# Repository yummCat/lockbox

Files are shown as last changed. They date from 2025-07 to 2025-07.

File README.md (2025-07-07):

# lockbox

The latest brilliant innovation we were able to come up with, was a box, that locks! 🤯

This device was meant to be small and cute, and importantly baby friendly. Designed for baby professionals, colloquially known as "Boss Babies" this device is meant to be carried around in a briefcase, unlocked with an RFID badge and four digit pin. In the process we learned a lot about RFID and how encryption worked(when we got sidetracked).

This project started with a schematic:



Next we made the pcb design:



Next we made the 3d model:


WhatsApp Image 2025-07-02 at 21 14 29_6d6b2fa8
WhatsApp Image 2025-07-07 at 18 49 21_a0b8ef6a

Lastly the BOM:


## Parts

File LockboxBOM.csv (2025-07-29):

Lockbox | Quantity | Net Cost | Links to buy stuff :)) | Shipping
Arduino Uno v3 | 1 | 14 | https://www.amazon.com/dp/B0B6VV7MS7?sp_csd=d2lkZ2V0TmFtZT1zcF9ocXBfc2hhcmVk | $0
RFID | 1 | 10 | https://www.amazon.com/HiLetgo-3pcs-RFID-Kit-Raspberry/dp/B07VLDSYRW/ | $0
Switches | 10 | 2.5 | https://www.adafruit.com/product/1119 | $4.90
Resistors | irrelevant | 6.5 | https://www.amazon.com/dp/B09N7NKX2Jhttps://www.amazon.com/California-JOS-Carbon-Resistor-Tolerance/dp/B0BR66LHWH/r | $0
Mosfet | 1 | 0.15 | https://www.addicore.com/products/2n7000-logic-level-n-channel-mosfet?variant=45759492948285 | $8
Charger | 1 | 1.25 | https://www.addicore.com/products/tp4056-tc4056a-lithium-battery-charger-and-protection-module | $0
Capacitors | irrelevant | 8 | (Prob can find cheaper)https://www.amazon.com/dp/B0DR8QRW1L/ref=sspa_dk_detail_5 | $0
Boost converter | 1 | 1.5 | https://www.addicore.com/products/mt3608-step-up-adjustable-dc-dc-switching-boost-converter | $0
Diodes | 3 | NA | NA
LiPO battery | 1 | 5.5 | (Prob can find cheaper)https://www.digikey.com/en/products/detail/us-electronics-inc./USE-702528-500PCBJST/15781479 | $20
Lock thing | 1 | 9 | https://www.amazon.com/Uxcell-a14092600ux0438-Actuator-Solenoid-Electromagnet/dp/B013DR655A/ | $0
3D printing |  | 27 |  | $0
Total: | $118 | 85.4 |  | $33

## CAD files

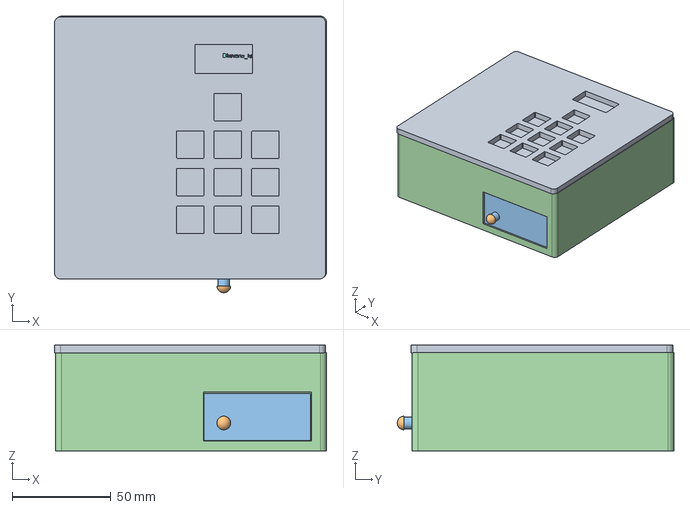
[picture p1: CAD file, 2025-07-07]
cad/Lockbox_complete.step
138.0 x 140.3 x 53.7 mm

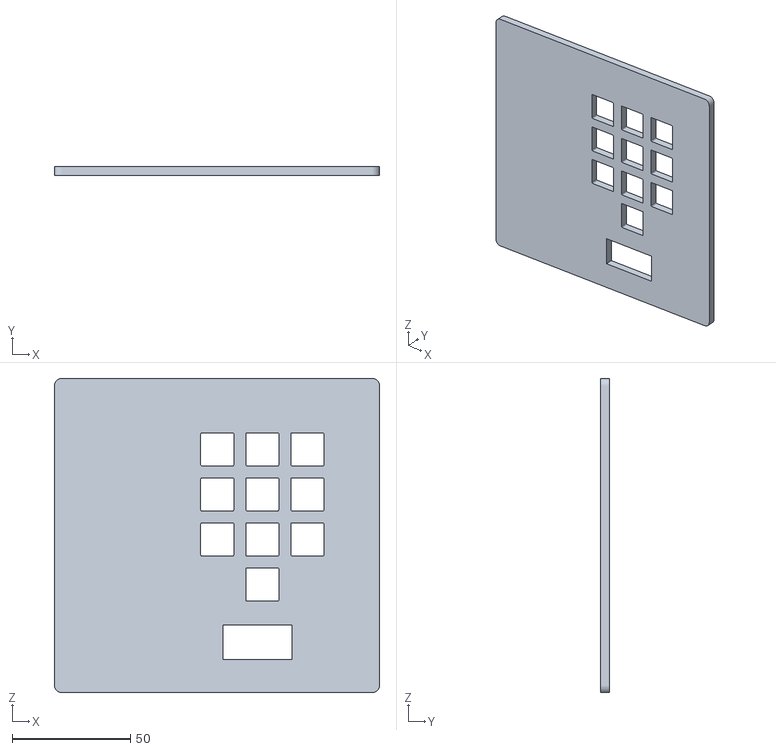
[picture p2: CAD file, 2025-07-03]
production/Lockbox_top.stl
137.5 x 4.00 x 132.8

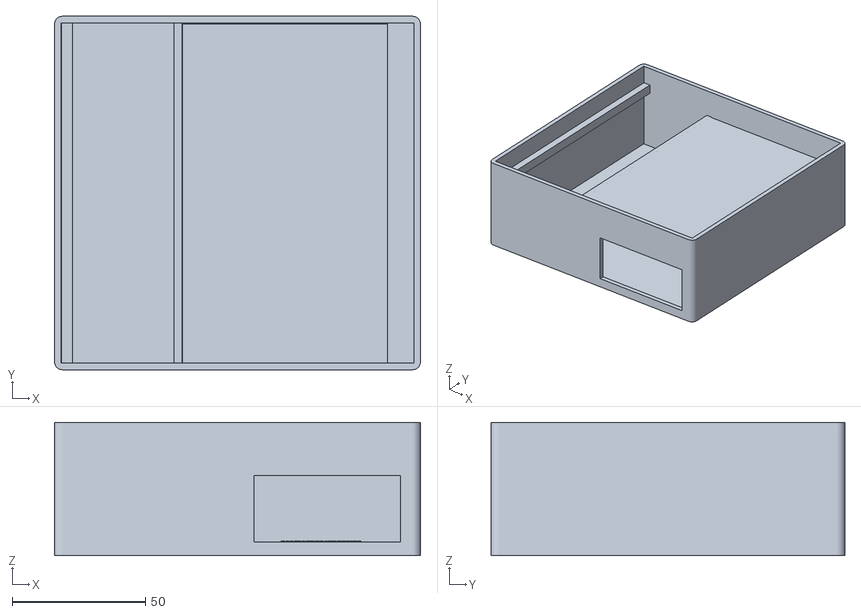
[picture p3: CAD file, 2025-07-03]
cad/Lockbox.stl
137.5 x 132.9 x 50.0

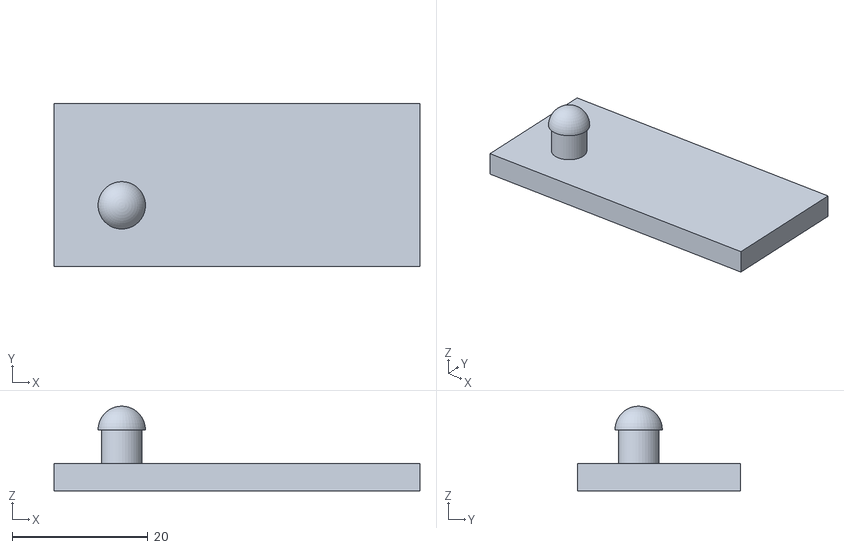
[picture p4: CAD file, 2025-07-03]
production/Door_for_locbox.stl
54.0 x 24.0 x 12.5

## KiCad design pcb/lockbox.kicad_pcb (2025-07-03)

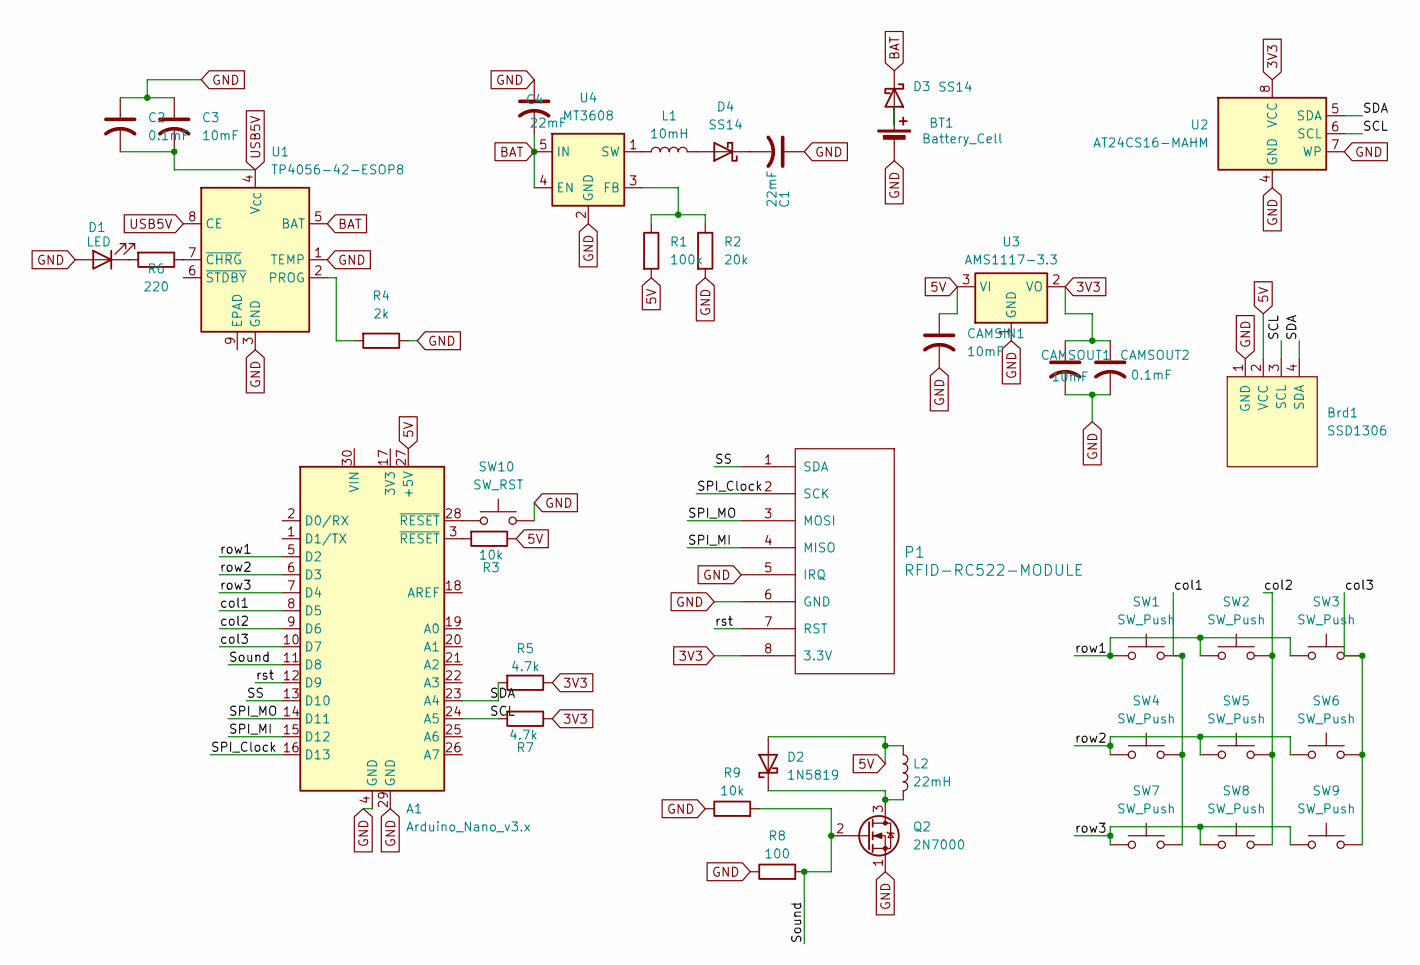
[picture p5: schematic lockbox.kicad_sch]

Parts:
A1: Arduino_Nano_v3.x; Arduino_Nano
BT1: Battery_Cell; JST_PH_S2B-PH-K_1x02_P2.00mm_Horizontal
Brd1: SSD1306; Adafruit_SSD1306
C1, C4: 22mF; CP_Radial_D5.0mm_P2.00mm
C2: 0.1mF; CP_Radial_D5.0mm_P2.50mm
C3: 10mF; CP_Radial_D5.0mm_P2.00mm
CAMSIN1: 10mF; CP_Radial_D5.0mm_P2.00mm
CAMSOUT1: 10mF; CP_Radial_D5.0mm_P2.00mm
CAMSOUT2: 0.1mF; CP_Radial_D5.0mm_P2.50mm
D1: LED; LED_D5.0mm
D2: 1N5819; D_DO-41_SOD81_P10.16mm_Horizontal
D3, D4: SS14; D_SMA
L1: 10mH; L_Axial_L26.0mm_D9.0mm_P5.08mm_Vertical_Fastron_77A
L2: 22mH; L_Axial_L26.0mm_D9.0mm_P5.08mm_Vertical_Fastron_77A
P1: RFID-RC522-MODULE; RC522_I2C_B30x20mm
Q2: 2N7000; TO-92L_Inline_Wide
R1: 100k; R_Axial_DIN0207_L6.3mm_D2.5mm_P7.62mm_Horizontal
R2: 20k; R_Axial_DIN0207_L6.3mm_D2.5mm_P7.62mm_Horizontal
R3, R9: 10k; R_Axial_DIN0207_L6.3mm_D2.5mm_P7.62mm_Horizontal
R4: 2k; R_Axial_DIN0207_L6.3mm_D2.5mm_P7.62mm_Horizontal
R5, R7: 4.7k; R_Axial_DIN0207_L6.3mm_D2.5mm_P7.62mm_Horizontal
R6: 220; R_Axial_DIN0207_L6.3mm_D2.5mm_P7.62mm_Horizontal
R8: 100; R_Axial_DIN0207_L6.3mm_D2.5mm_P7.62mm_Horizontal
SW1, SW2, SW3, SW4, SW5, SW6, SW7, SW8, SW9: SW_Push; SW_Cherry_MX_1.00u_PCB
SW10: SW_RST; SW_Cherry_MX_1.00u_PCB
U1: TP4056-42-ESOP8; SOIC-8-1EP_3.9x4.9mm_P1.27mm_EP2.41x3.3mm_ThermalVias
U2: AT24CS16-MAHM; DFN-8-1EP_3x2mm_P0.5mm_EP1.3x1.5mm
U3: AMS1117-3.3; SOT-223-3_TabPin2
U4: MT3608; SOT-23-6

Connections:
3V3: CAMSOUT1.1, CAMSOUT2.1, P1.8 (3.3V), R5.1, R7.1, U2.8 (VCC), U3.2 (VO)
5V: A1.27 (+5V), Brd1.2 (VCC), CAMSIN1.1, D2.2 (A), L2.1, R1.2, R3.1, U3.3 (VI)
/SCL: A1.24 (A5), Brd1.3 (SCL), R7.2, U2.6 (SCL)
/SDA: A1.23 (A4), Brd1.4 (SDA), R5.2, U2.5 (SDA)
/SPI_Clock: A1.16 (D13), P1.2 (SCK)
/SPI_MI: A1.15 (D12), P1.4 (MISO)
/SPI_MO: A1.14 (D11), P1.3 (MOSI)
/SS: A1.13 (D10), P1.1 (SDA)
/Sound: A1.11 (D8), Q2.2 (G), R8.2, R9.2
/col1: A1.8 (D5), SW1.2, SW4.2, SW7.2
/col2: A1.9 (D6), SW2.2, SW5.2, SW8.2
/col3: A1.10 (D7), SW3.2, SW6.2, SW9.2
/row1: A1.5 (D2), SW1.1, SW2.1, SW3.1
/row2: A1.6 (D3), SW4.1, SW5.1, SW6.1
/row3: A1.7 (D4), SW7.1, SW8.1, SW9.1
/rst: A1.12 (D9), P1.7 (RST)
BAT: C4.2, D3.1 (K), U1.5 (BAT), U4.4 (EN), U4.5 (IN)
GND: A1.4 (GND), A1.29 (GND), BT1.2 (-), Brd1.1 (GND), C1.1, C2.1, C3.1, C4.1, CAMSIN1.2, CAMSOUT1.2, CAMSOUT2.2, D1.2 (A), P1.5 (IRQ), P1.6 (GND), Q2.1 (S), R2.2, R4.1, R8.1, R9.1, SW10.2, U1.1 (TEMP), U1.3 (GND), U2.4 (GND), U2.7 (WP), U3.1 (GND), U4.2 (GND)
unnamed: A1.3 (~RESET), R3.2
unnamed: A1.28 (~RESET), SW10.1
unnamed: BT1.1 (+), D3.2 (A)
unnamed: D1.1 (K), R6.2
unnamed: D2.1 (K), L2.2, Q2.3 (D)
unnamed: D4.2 (A), L1.2
unnamed: C1.2, D4.1 (K)
unnamed: R4.2, U1.2 (PROG)
unnamed: R6.1, U1.7 (~CHRG)
unnamed: R1.1, R2.1, U4.3 (FB)
unnamed: L1.1, U4.1 (SW)
USB5V: C2.2, C3.2, U1.4 (V_{CC}), U1.8 (CE)

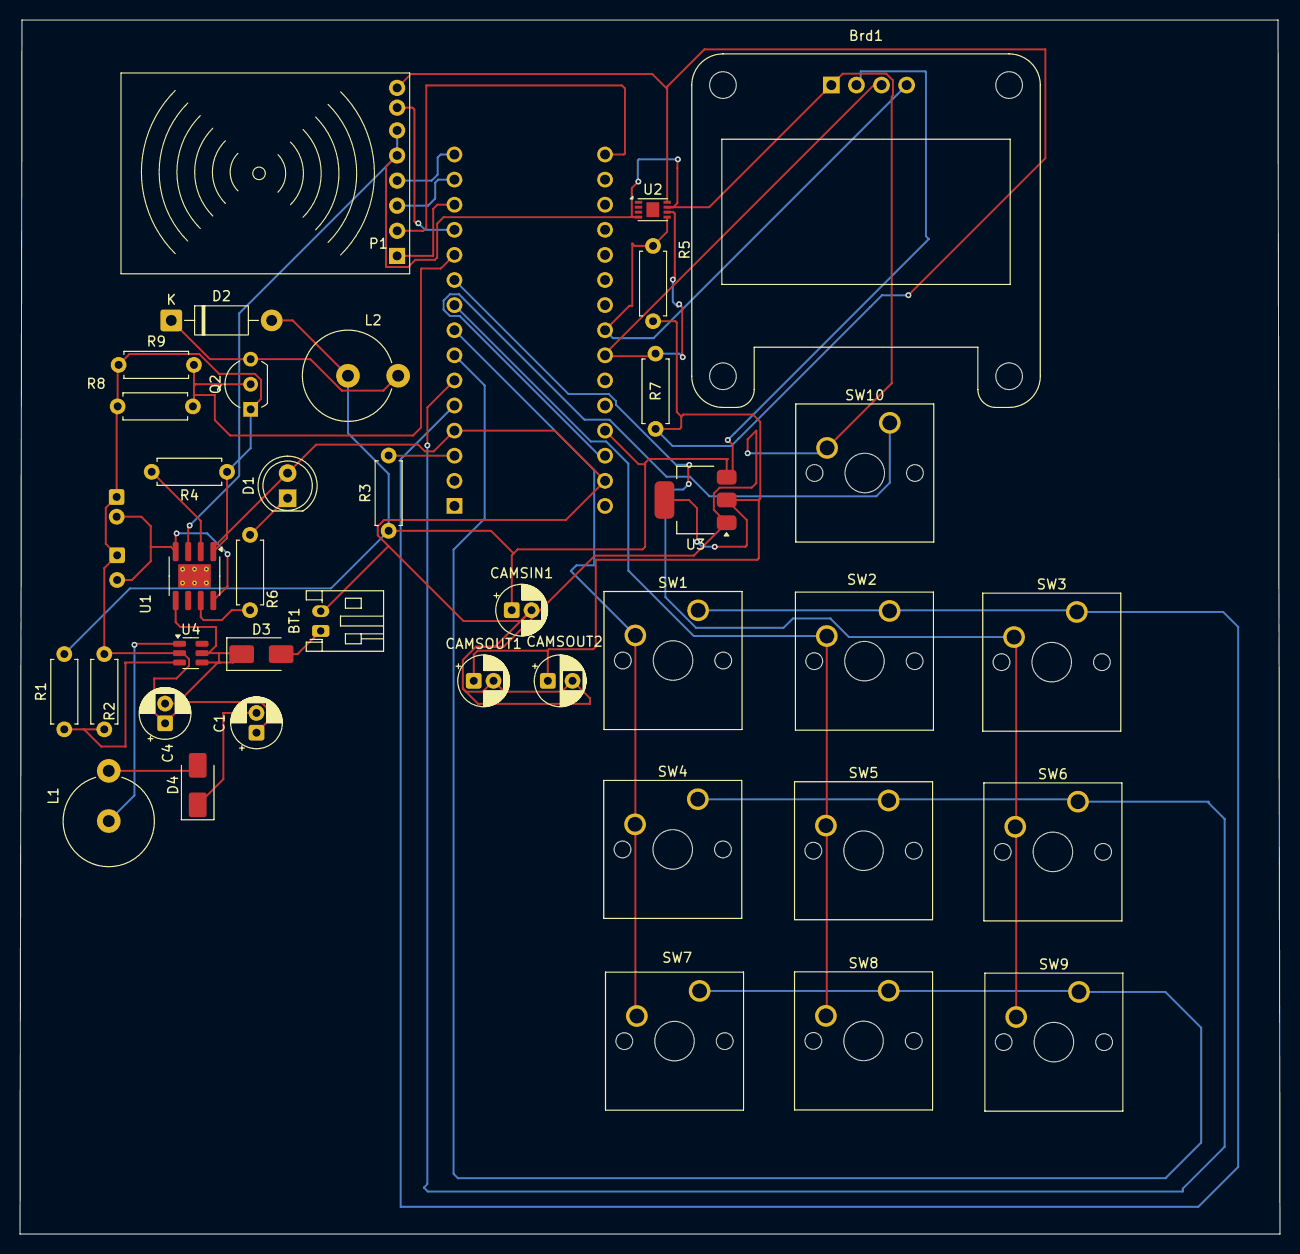
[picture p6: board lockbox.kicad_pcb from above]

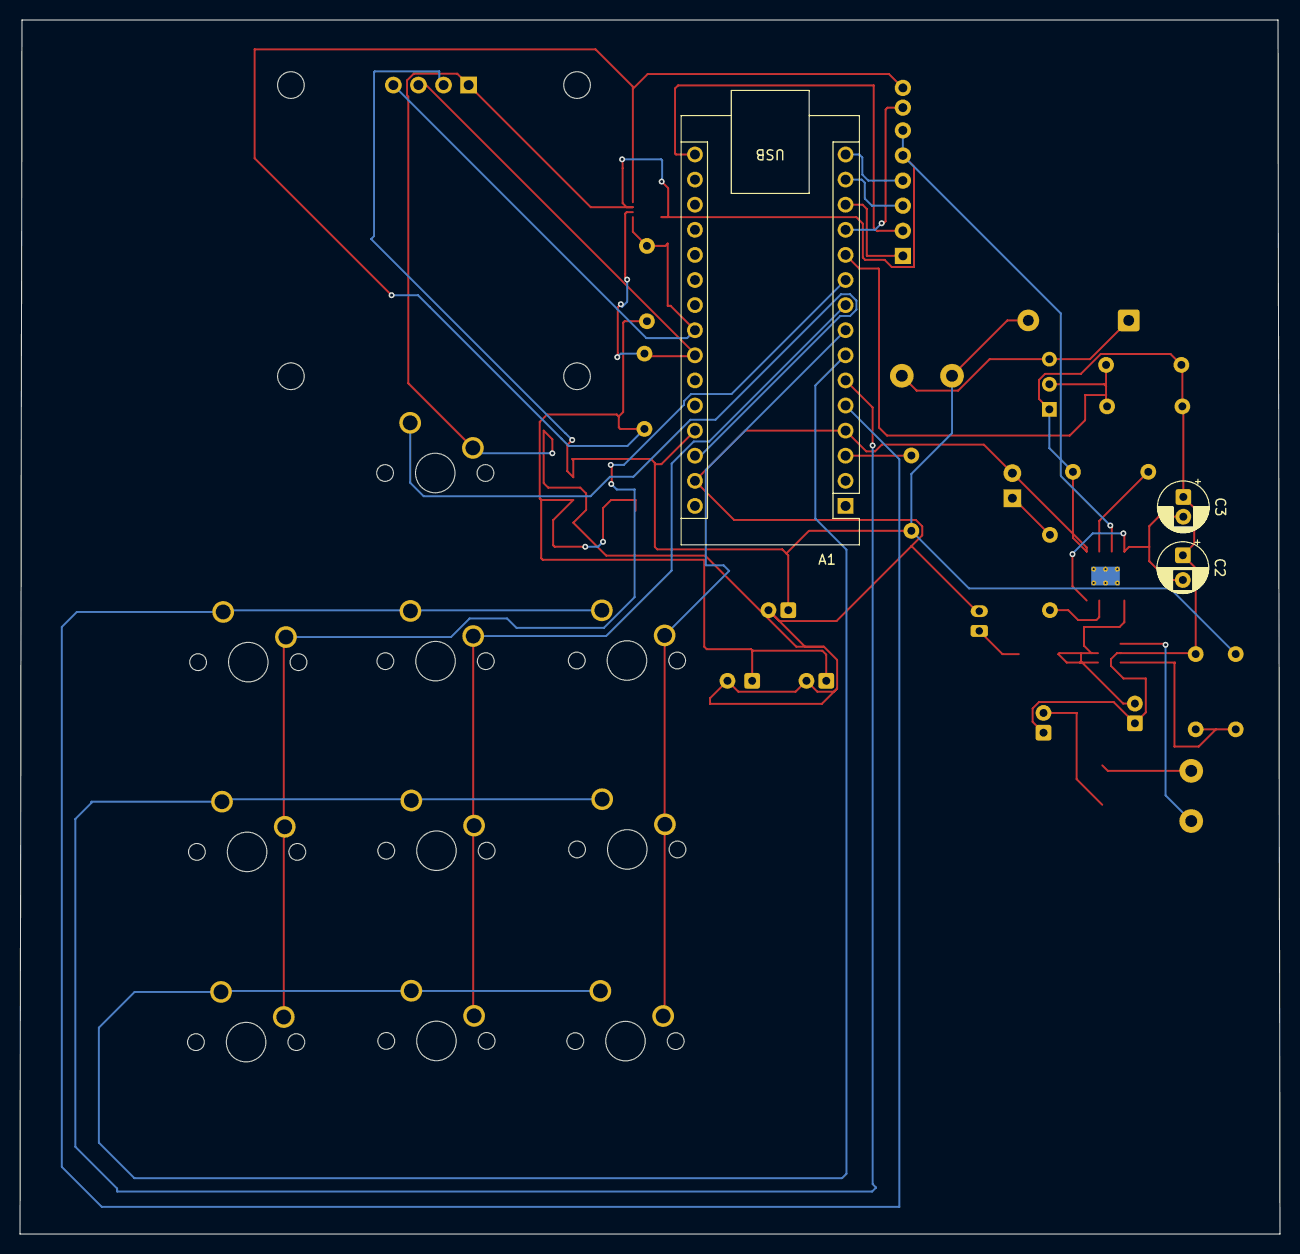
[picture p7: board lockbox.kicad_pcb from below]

Board: 2 copper layers, 127.5 x 122.8 mm, 41 parts (3 on the bottom side), 30 nets.

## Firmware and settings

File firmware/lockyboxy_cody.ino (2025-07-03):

#include <Wire.h>
#include <SPI.h>
#include <MFRC522.h>
#include <Keypad.h>

// Pin Definitions ----------
#define RST_PIN        8
#define SS_PIN         10
#define LOCK_PIN       6
#define RESET_BTN_PIN  9

// EEPROM Definitions ----------
#define EEPROM_ADDR 0x50
#define EEPROM_PIN_ADDR 0x0000

// RFID Setup ----------
MFRC522 mfrc522(SS_PIN, RST_PIN);

// You can add more tags here (4-byte UIDs)
byte validTags[][4] = {
  {0xDE, 0xAD, 0xBE, 0xEF},
  {0x12, 0x34, 0x56, 0x78}
};
const int numTags = sizeof(validTags) / sizeof(validTags[0]);

// ---------- Keypad Setup ----------
const byte ROES = 3, CULS = 3;
char keys[ROES][CULS] = {
  {'1','2','3'},
  {'4','5','6'},
  {'7','8','9'},
};
byte rowPins[ROES] = {D2, D3, D4};
byte colPins[CULS] = {D5, D6, D7};
Keypad keypad = Keypad(makeKeymap(keys), rowPins, colPins, ROES, CULS);

// ---------- State Variables ----------
char storedPIN[5] = "0000";
char enteredPIN[5];
int pinIndex = 0;
unsigned long unlockTime = 0;
const unsigned long UNLOCK_DURATION = 5000;

void setup() {
  Serial.begin(9600);
  SPI.begin();
  mfrc522.PCD_Init();
  Wire.begin();

  pinMode(LOCK_PIN, OUTPUT);
  pinMode(RESET_BTN_PIN, INPUT_PULLUP);

  lockBox();
  loadPINFromEEPROM();
}

void loop() {
  // RFID Unlock
  if (checkRFID()) {
    unlockBox();
    delay(1000);
  }

  // PIN Input
  enteredPIN[pinIndex] = '\0';
  char key = keypad.getKey();
  if (key && isDigit(key)) {
    enteredPIN[pinIndex++] = key;
    if (pinIndex == 4) {
      enteredPIN[4] = '\0';
      if (strcmp(enteredPIN, storedPIN) == 0) {
        unlockBox();
      }
      else{
        Serial.println("Lock in brother. Wrong pin :(");
      }
      pinIndex = 0;
    }
  }

  // Reset Button
  if (digitalRead(RESET_BTN_PIN) == LOW) {
    delay(1000);
    if (digitalRead(RESET_BTN_PIN) == LOW) {
      enterResetMode();
    }
  }

  // Auto Re-lock
  if (digitalRead(LOCK_PIN) == HIGH && millis() - unlockTime > UNLOCK_DURATION) {
  lockBox();
  }
}

// Lock Control ----------
void unlockBox() {
  digitalWrite(LOCK_PIN, HIGH);
  unlockTime = millis();
  Serial.println("Unlocked!");
}

void lockBox() {
  digitalWrite(LOCK_PIN, LOW);
}

// RFID Functions ----------
bool checkRFID() {
  if (!mfrc522.PICC_IsNewCardPresent() || !mfrc522.PICC_ReadCardSerial())
    return false;

  for (int t = 0; t < numTags; t++) {
    bool match = true;
    for (int i = 0; i < 4; i++) {
      if (mfrc522.uid.uidByte[i] != validTags[t][i]) {
        match = false;
        break;
      }
    }
    if (match) {
      Serial.println("RFID matched");
      mfrc522.PICC_HaltA();
      return true;
    }
  }
  mfrc522.PICC_HaltA();
  return false;
}

// EEPROM Functions ----------
void savePINToEEPROM(char* pin) {
  Wire.beginTransmission(EEPROM_ADDR);
  Wire.write((EEPROM_PIN_ADDR >> 8) & 0xFF);
  Wire.write(EEPROM_PIN_ADDR & 0xFF);
  for (int i = 0; i < 4; i++) {
    Wire.write(pin[i]);
  }
  Wire.endTransmission();
  delay(10);
  memcpy(storedPIN, pin, 5);
}

void loadPINFromEEPROM() {
  Wire.beginTransmission(EEPROM_ADDR);
  Wire.write((EEPROM_PIN_ADDR >> 8) & 0xFF);
  Wire.write(EEPROM_PIN_ADDR & 0xFF);
  Wire.endTransmission();

  Wire.requestFrom(EEPROM_ADDR, 4);
  for (int i = 0; i < 4; i++) {
    if (Wire.available()) {
      storedPIN[i] = Wire.read();
    }
  }
  storedPIN[4] = '\0';
  Serial.print("Stored PIN: ");
  Serial.println(storedPIN);
}

// Reset Mode ----------
void enterResetMode() {
  Serial.println("Resetting PIN. Enter new 4-digit PIN:");
  char newPIN[5];
  int idx = 0;
  while (idx < 4) {
    char k = keypad.getKey();
    if (k && isDigit(k)) {
      newPIN[idx++] = k;
      Serial.print('*'); // mask entry
    }
  }
  newPIN[4] = '\0';
  savePINToEEPROM(newPIN);
  Serial.println("\nNew PIN saved!");

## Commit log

2025-07-01 Added folders
    [EMO (1).stp, Top_case_emoji.stp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]
2025-07-01 oopsie daisy weird folder placement
    [starter-B_Cu.gbl, starter-B_Mask.gbs, starter-B_Paste.gbp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]
2025-07-03 added cad files
    [Door_for_locbox.stl, Lockbox.stl, Lockbox_top.stl]
2025-07-03 adding stuff to production
    [EMO (1).stp, Top_case_emoji.stp]
2025-07-03 Add gerbers, top case, EMO STPs, and firmware to production folder
    [Door_for_locbox.stl, Lockbox.stl, Lockbox_top.stl]
2025-07-03 Restore lockbox production files
    [Door_for_locbox.stl, EMO (1).stp, Lockbox.stl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]
2025-07-07 added complete cad file
    [Lockbox_complete.step]
2025-07-29 added bom csv file
    [LockboxBOM.csv]
